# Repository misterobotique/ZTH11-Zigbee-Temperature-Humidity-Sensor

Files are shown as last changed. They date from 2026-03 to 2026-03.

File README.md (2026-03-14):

# ZTH11-Zigbee-Temperature-Humidity-Sensor
Here you will find the result of my reverse engineering of a cheap Zigbee temperature & humidity sensor PCB (marking: ZTH11-ZTY-V1.2, dated 2025-10-13).  
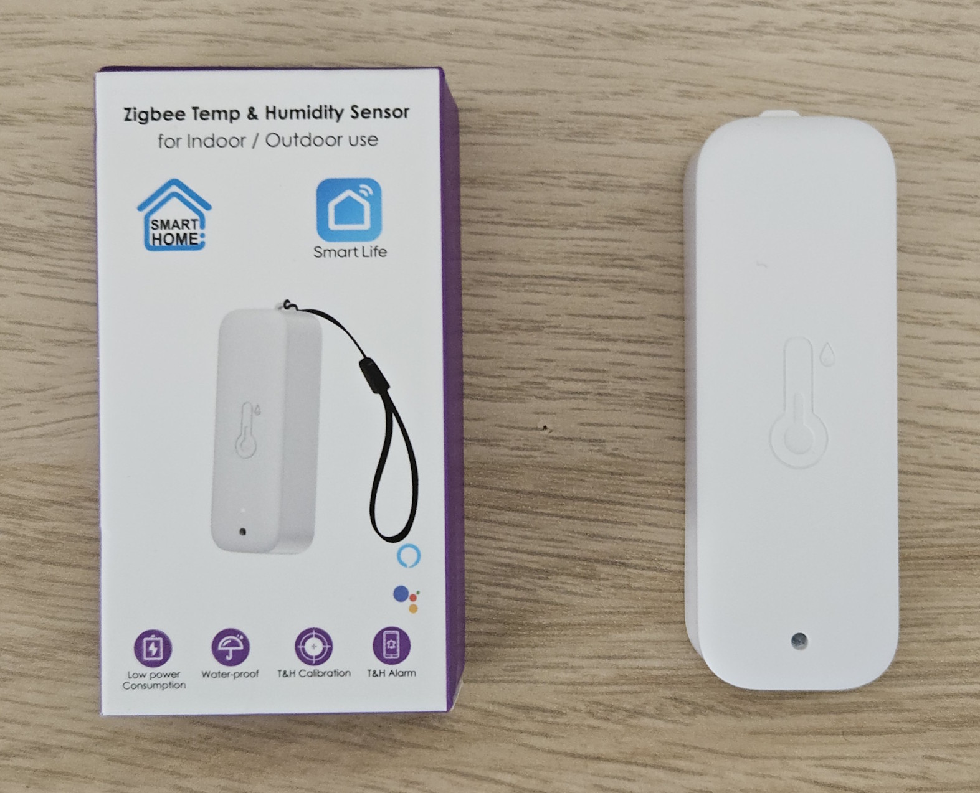
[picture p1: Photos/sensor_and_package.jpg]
photo of Zigbee sensor
  

---

## Photos
Photos taken before and during disassembly:  
・Sensor and its package  
・PCB top side  
・PCB top side (U3 removed)  
・PCB bottom side

## Datasheets
Datasheets for the main components, for reference.

## Schematic
Schematic of the actual PCB, drawn from visual inspection. Connections confirmed using a multimeter in continuity mode.  
KiCad project files and PDF.

## BOM
Resistor values measured in-circuit. Capacitors were desoldered and measured out-of-circuit.

## Firmware

### Original Firmware
Original firmware dumped from the ZTU module using a CH340G-based UART-to-USB adapter and [TlsrComSwireWriter](https://github.com/pvvx/TlsrComSwireWriter).
> ⚠️ The Zigbee Network Key originally found at address `0x000DC218` (16 bytes) has been replaced with a randomly generated sequence before publishing.

### Custom Firmware
`ZTH01Z_v0135_CHT8310_patched.bin` is based on [pvvx/ZigbeeTLc](https://github.com/pvvx/ZigbeeTLc) ZTH01Z_v0135 with two bug fixes applied to `sensors.c` to enable CHT8310/CHT8315 sensor support:
- Fix VID byte-swap: `CHT8215_VID 0x1582` → `0x8215`
- Fix reset stabilization delay: `sleep_us(190)` → `sleep_us(1000)`

See [ZigbeeTLc issue #272](https://github.com/pvvx/ZigbeeTLc/issues/272) for details.

Flash using [USBCOMFlashTx](https://pvvx.github.io/ATC_MiThermometer/USBCOMFlashTx.html).

Requires the following hardware modification:
- Remove U3
- Bridge pins 1 and 14 at U3 footprint to power the CHT8310
- Connect ZTU module GPIOs as follows:

| ZTU GPIO | Function |
|---|---|
| GPIO_PB4 | KEY |
| GPIO_PB5 | LED |
| GPIO_PC2 | SDA |
| GPIO_PC3 | SCL |

See [pcb_top_modif.jpg](Photos/pcb_top_modif.jpg) for a photo of the completed hardware modification.

---

## Measurements
Power consumption recorded after successful pairing.

| Phase | Current |
|---|---|
| Idle (standby) | 5.2 µA |
| Sending data | 170.25 µA |

Screenshots:  
・Idle current (linear scale)  
・Idle current (log scale)  
・Current when sending data (log scale)

---

## Analysis

### I2C — Unknown IC ↔ CHT8310

The humidity & temperature sensor communicates over I2C with U3, an unidentified IC.  
The captured transaction sequence is documented in:  
📄 [analysis/i2c_cht8310.pdf](Analysis/i2c_cht8310.pdf)

### UART — Unknown IC ↔ ZTU Module

The ZTU module communicates with the same unidentified IC over UART.  
Two captures are provided:  
- 📄 [analysis/uart_ztu_idle.pdf](Analysis/uart_ztu_idle.pdf) — transactions during normal standby (without pairing)
- 📄 [analysis/uart_ztu_pairing.pdf](Analysis/uart_ztu_pairing.pdf) — transactions including the full pairing sequence

---

## Sensor Behavior

### Data Reporting Interval

**According to the manual:**  
・If temperature changes by ≥ 0.5°C or humidity by ≥ 5%, data is updated every 2 minutes.  
・If temperature changes by < 0.5°C or humidity by < 5%, data is updated once an hour.  

**Observed in practice:**  
・A report is sent immediately when either value changes by one step (0.5°C for temperature, 1% for humidity).  
・The minimum inter-report interval appears to be around 2 minutes.  
・When no value changes, a forced report is sent after approximately 1 hour.  

---

## Tools & Equipment

| Purpose | Tool |
|---|---|
| Logic analysis | Saleae Logic 8 |
| Current measurement | Nordic Power Profiler Kit II (PPK2) |
| R, C measurement | LCR meter DER EE DE-5000 |

---

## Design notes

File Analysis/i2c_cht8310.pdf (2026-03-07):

## I2C transactions: unknown IC ↔ CHT8310

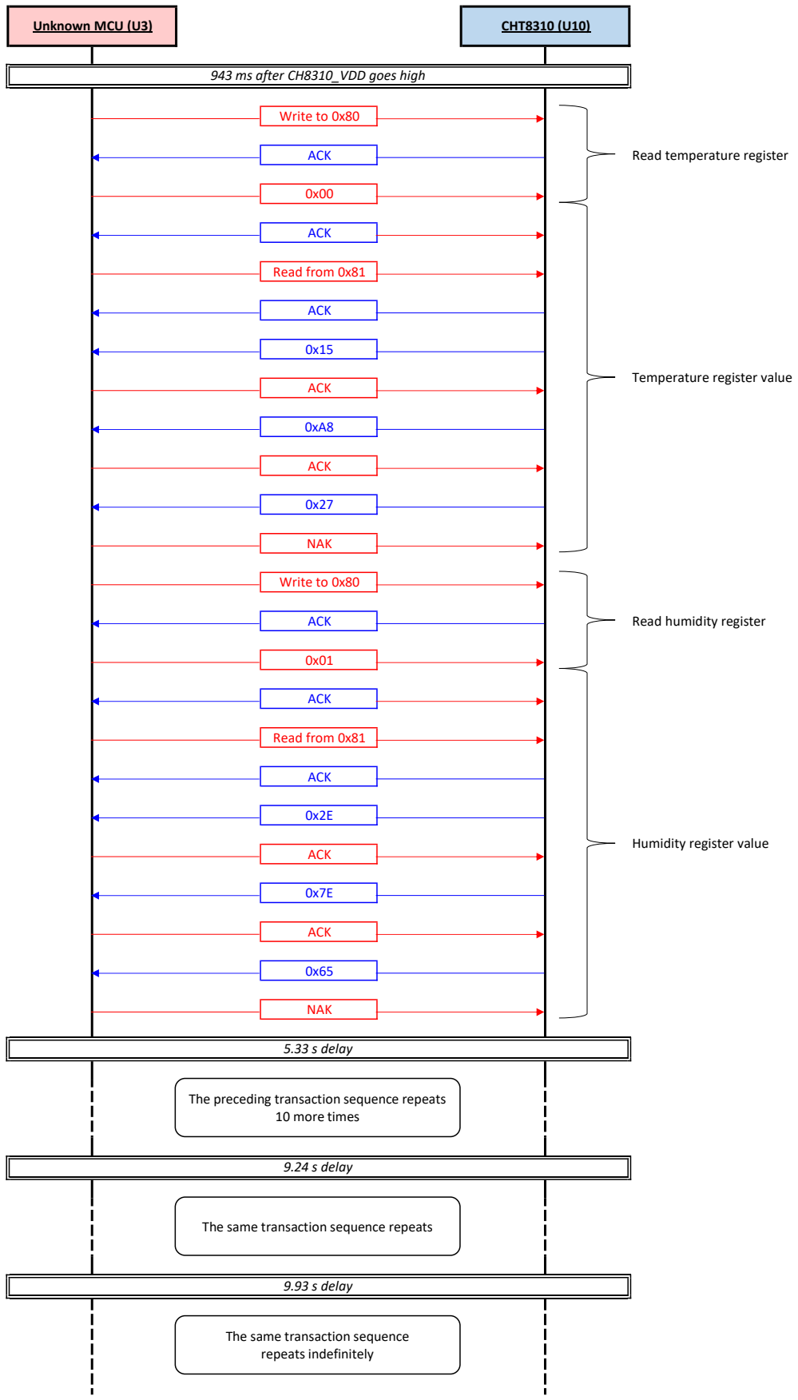
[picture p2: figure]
Write to 0x80; ACK; Read temperature register; Read from 0x81; NAK; Read humidity register; Temperature register value; Humidity register value; 9.24 s delay; 9.93 s delay; Unknown MCU (U3); CHT8310 (U10); 943 ms after CH8310_VDD goes high; 5.33 s delay; The preceding transaction sequence repeats 10 more times; The same transaction sequence repeats; The same transaction sequence repeats indefinitely

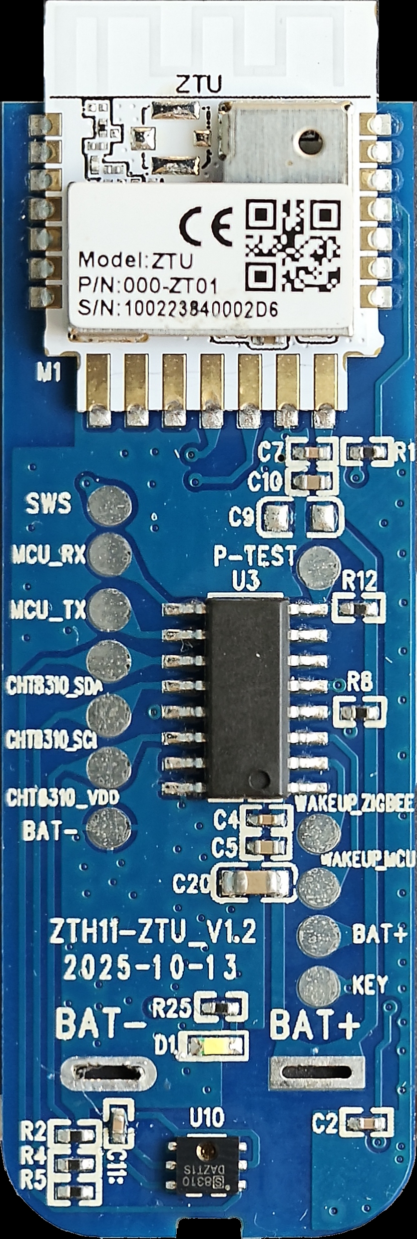
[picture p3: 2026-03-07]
Photos/pcb_top.jpg

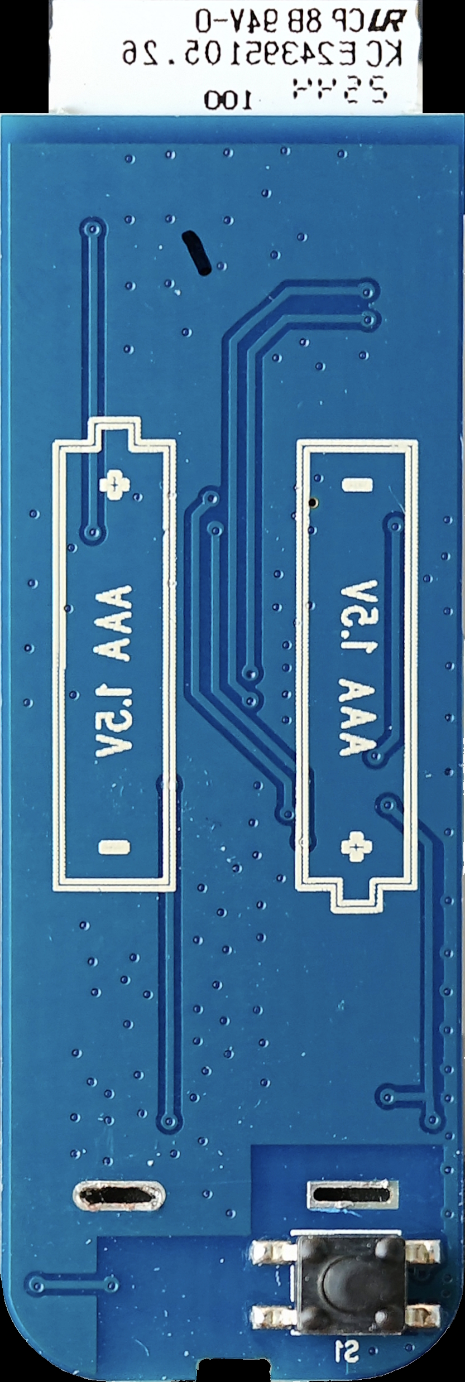
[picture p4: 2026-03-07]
Photos/pcb_bottom.jpg

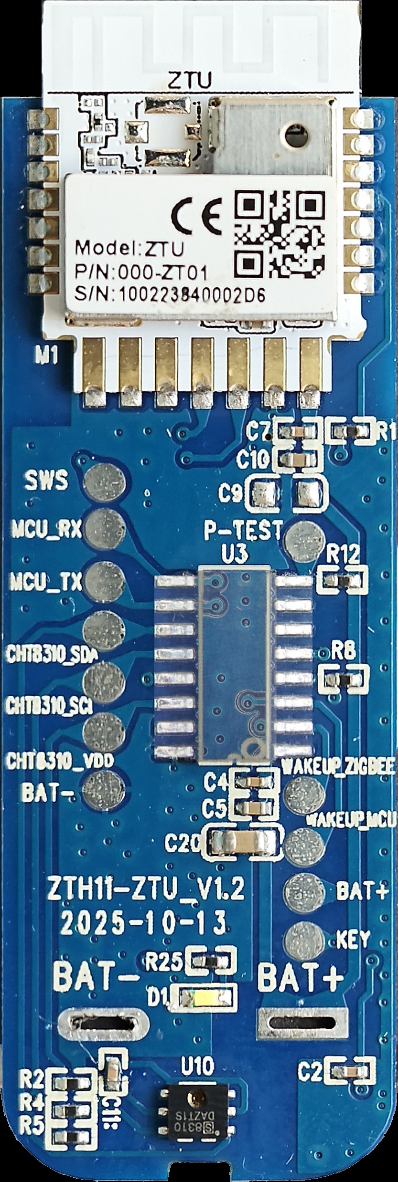
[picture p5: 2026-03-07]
Photos/pcb_top_no_U3.jpg

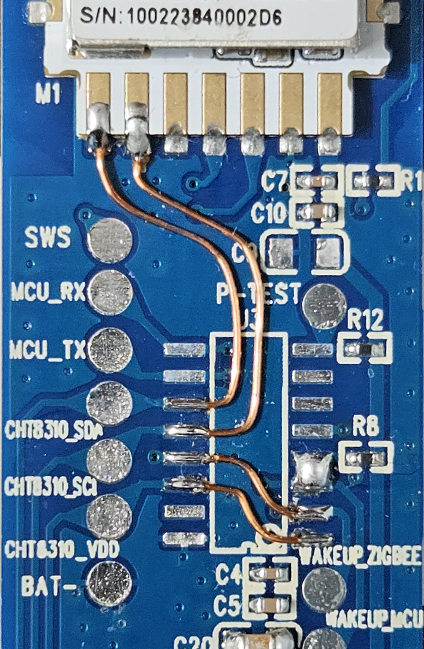
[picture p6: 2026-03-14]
Photos/pcb_top_modif.jpg

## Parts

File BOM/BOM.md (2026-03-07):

| Designator | Description | Part Number |
|---|---|---|
| C2 | Capacitor, 100nF | — |
| C4 | Capacitor, 100nF | — |
| C5 | Capacitor, 10µF | — |
| C7 | Capacitor, 100nF | — |
| C10 | Capacitor, 10µF | — |
| C11 | Capacitor, 100nF | — |
| C20 | Capacitor, 22µF | — |
| D1 | White LED | — |
| M1 | Zigbee module | ZTU |
| R1 | Resistor, 0Ω | — |
| R2 | Resistor, 330Ω | — |
| R4 | Resistor, 4.7kΩ | — |
| R5 | Resistor, 4.7kΩ | — |
| R8 | Resistor, 1kΩ | — |
| R12 | Resistor, 10kΩ | — |
| R25 | Resistor, 470Ω | — |
| S1 | Push button | — |
| U3 | Low power microcontroller | unknown |
| U10 | Temperature & humidity sensor | CHT8310 |

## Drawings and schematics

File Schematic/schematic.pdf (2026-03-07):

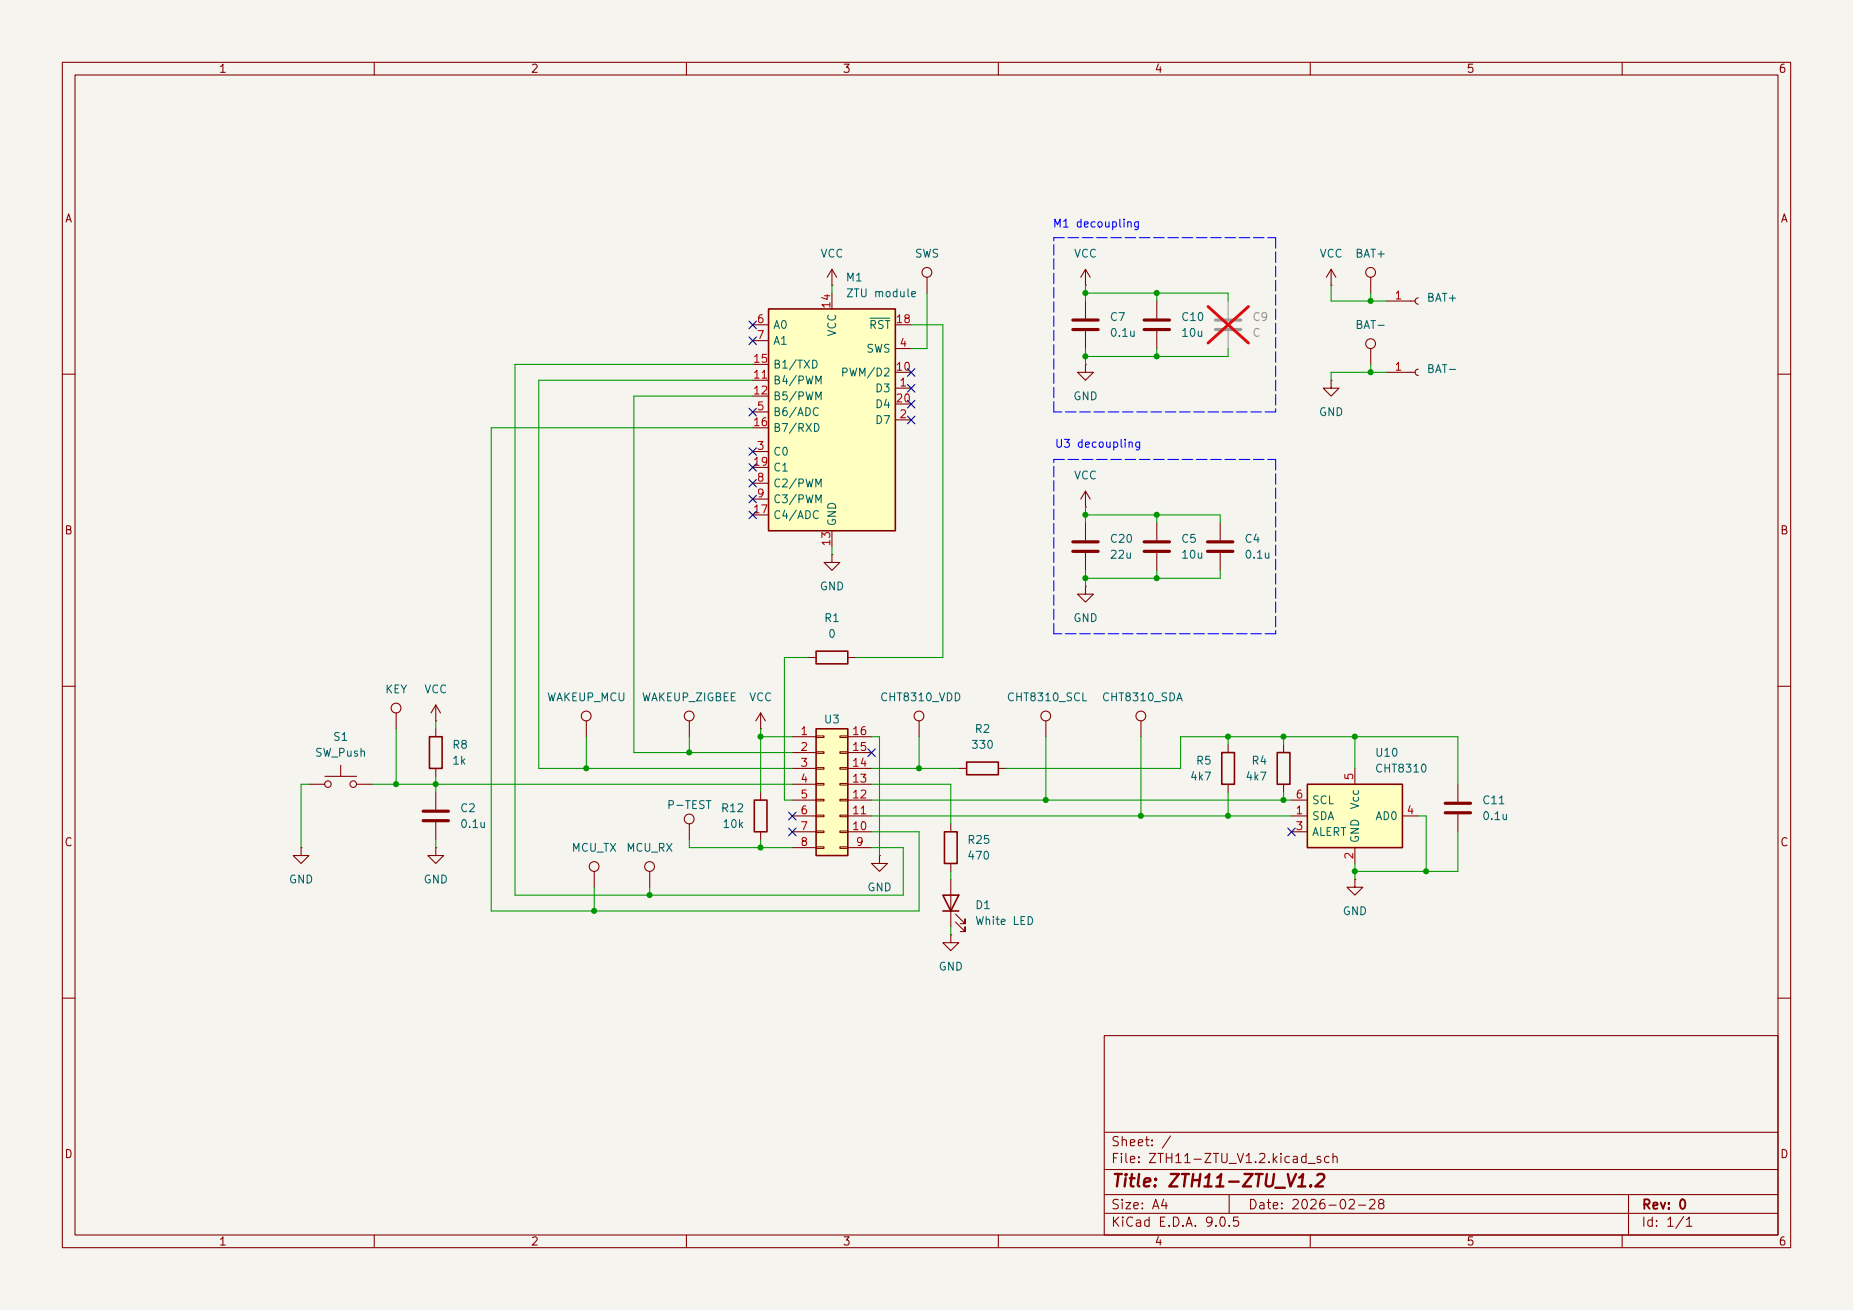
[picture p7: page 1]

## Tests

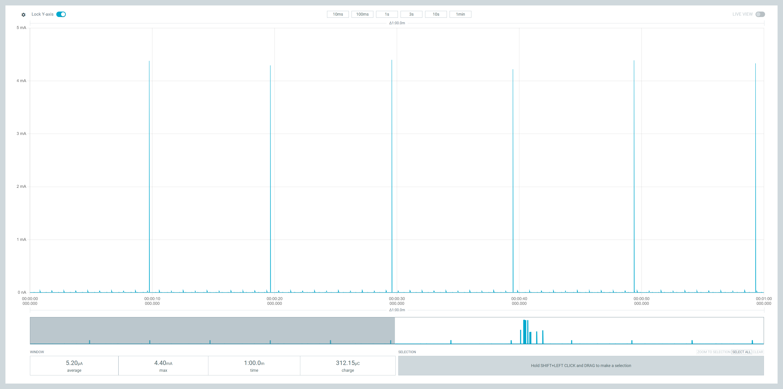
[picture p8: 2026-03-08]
Measurements/idle.png

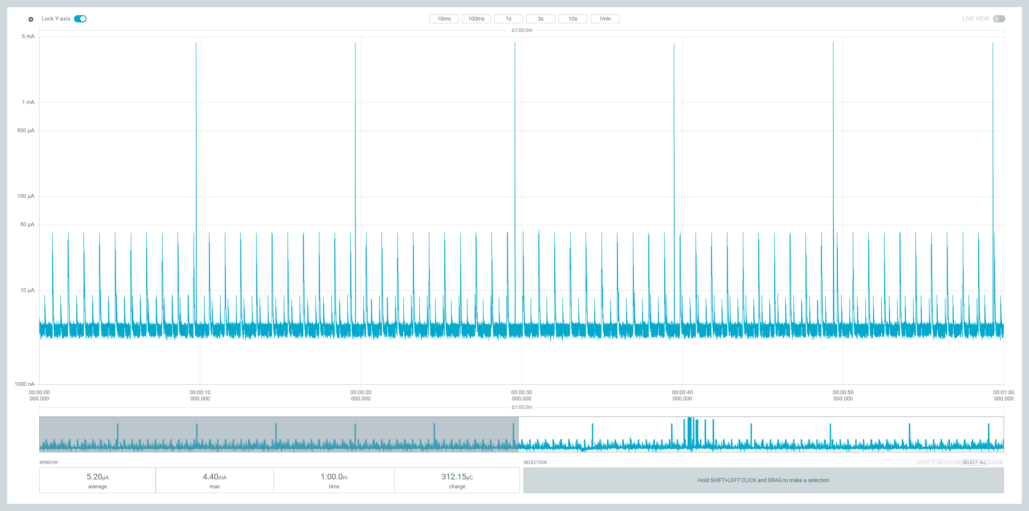
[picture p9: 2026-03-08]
Measurements/idle(log_scale).png

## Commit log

2026-03-07 Add README
    Initial README covering schematic, datasheets, photos, BOM, firmware, analysis, and tools used.
2026-03-07 Add photos
    Add photos of the sensor and its package, the top PCB side , the bottom PCB side and the top PCB side without U3
2026-03-07 Add datasheets
    Add datasheets for temperature and humidity sensor CH8310, Zigbee module ZTU.
2026-03-07 Add Bill of Materials (BOM) documentation
2026-03-07 Add I2C and UART transaction sequence analysis
2026-03-07 Add PDF of schematic
2026-03-07 Add Kicad schematic
    Add Kicad schematic along with custom symbol library
    [ZTH11-ZTU_V1.2.kicad_sch]
2026-03-07 Add correct Kicad files
2026-03-07 Add corrected schematic (PDF file)
2026-03-07 Add Measurements section to README
    Added a section for future current consumption measurements.
2026-03-07 Add missing capacitor entries to BOM
2026-03-08 Add screenshots of current measurements
    Current measurement was performed after pairing. The current was measured during idle mode and while sending data.
2026-03-08 Update README with power consumption and sensor behavior
    Added power consumption measurements and sensor behavior details.
2026-03-11 Add patched ZTH01Z firmware with CHT8310 support
    Based on pvvx/ZigbeeTLc ZTH01Z_v0135 with two bug fixes applied to sensors.c to enable CHT8310/CHT8315 sensor support:
    - Fix VID byte-swap: CHT8215_VID 0x1582 → 0x8215
    - Increase reset stabilization delay: sleep_us(190) → sleep_us(1000)
2026-03-14 Add photo of pcb top side modification
    Photo of the hardware modification for custom firmware
